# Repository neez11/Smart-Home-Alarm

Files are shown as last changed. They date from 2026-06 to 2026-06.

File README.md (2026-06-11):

# Smart Home Alarm

A local smart home alarm built with Raspberry Pi Zero WH, featuring PIR motion detection, LED and buzzer alarm feedback, Zigbee/MQTT door monitoring, camera support, a web dashboard and custom PCB design.

---

# Development
This project was developed as a group project in Electrical Engineering.

Contributors:
- [@neez11](https://github.com/neez11)
- [@abbefakih](https://github.com/abbefakih)
- [@MarcusAtaseven](https://github.com/MarcusAtaseven)
- [@Samy-Jomma](https://github.com/Samy-Jomma)

---

## Overview

This project is a smart home alarm prototype designed to run **locally without cloud services**.  
It combines embedded hardware, wireless communication, backend logic, a web-based dashboard, PCB design, and a 3D-printed enclosure into one complete system.

The system is built around a **Raspberry Pi Zero WH** and can:

- detect motion using a PIR sensor
- detect door/window events using a Zigbee sensor
- trigger local alarm feedback using LED and buzzer
- log events in the backend
- show live status in a web dashboard
- display a camera feed during alarm events
- run locally without relying on external cloud platforms

---

## Final Product

### Final assembled product
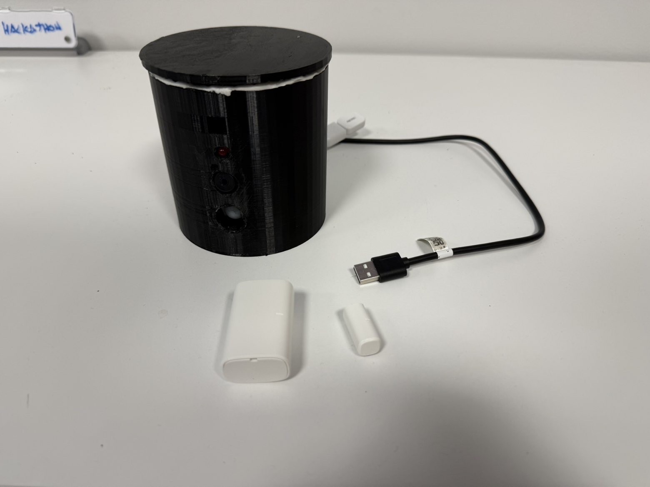
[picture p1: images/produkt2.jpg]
Final Product


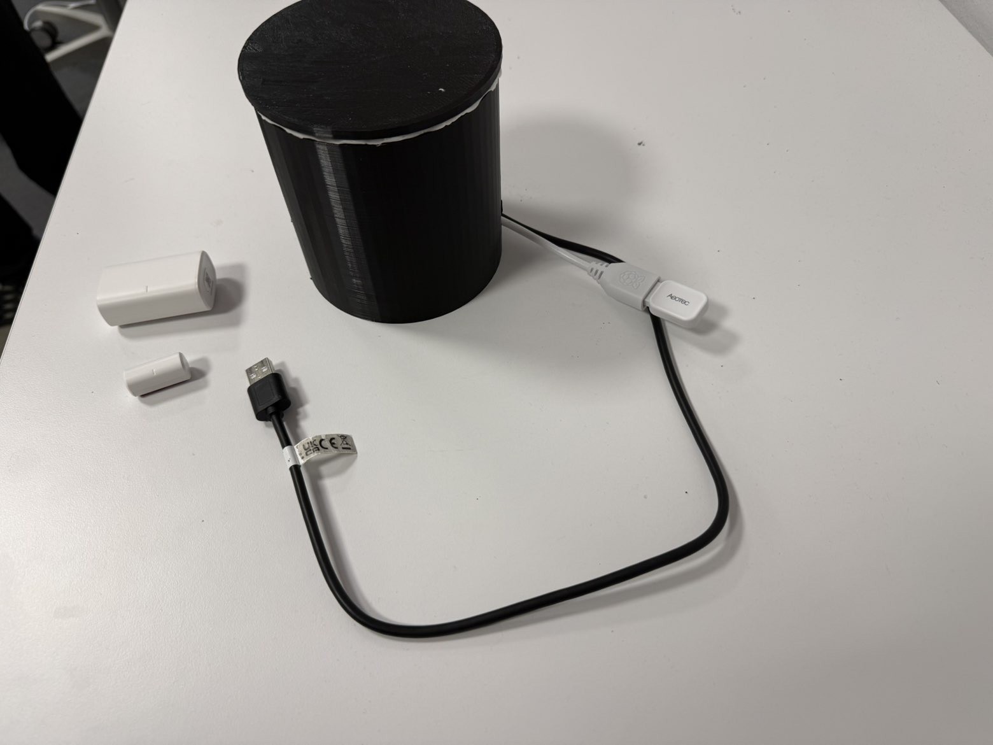
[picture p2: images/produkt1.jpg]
Final Product View


---

## Hardware Components

- Raspberry Pi Zero WH
- PIR sensor
- LED
- buzzer
- 220 Ω resistors
- SONOFF SNZB-04P Zigbee door/window sensor
- Zigbee USB adapter
- micro-USB OTG adapter
- Raspberry Pi camera module
- custom PCB
- 3D-printed enclosure

---

## System Architecture

The project is divided into the following parts:

### Local Hardware
- PIR sensor
- LED
- buzzer
- Raspberry Pi GPIO connections
- custom PCB

### Wireless Sensor Layer
- Zigbee door/window sensor
- Zigbee USB gateway
- Zigbee2MQTT
- MQTT messaging

### Software
- Python backend
- alarm logic
- event logging
- camera service
- REST API

### User Interface
- React/Vite frontend
- live system status
- event timeline
- control buttons
- camera view

### Deployment
- local hosting on Raspberry Pi
- Nginx as web server / reverse proxy

---

## Hardware Prototype

### Prototype wiring and components
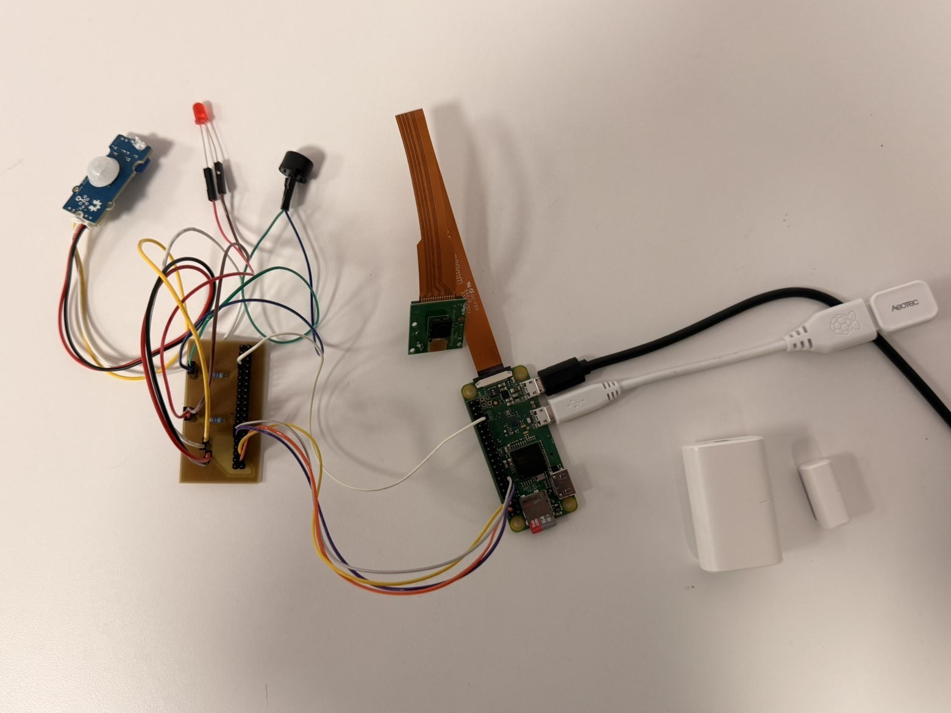
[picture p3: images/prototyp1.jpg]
Prototype


### Raspberry Pi GPIO reference
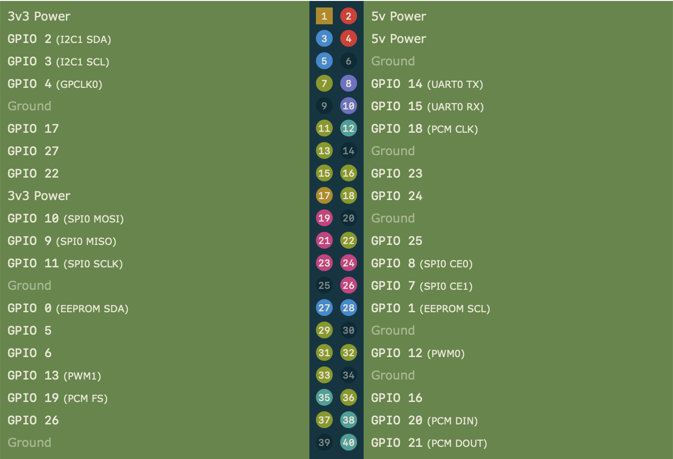
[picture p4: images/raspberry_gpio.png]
GPIO Pinout


---

## Schematic and PCB Design

The PCB was designed in **KiCad** based on the local hardware part of the system.

### KiCad schematic
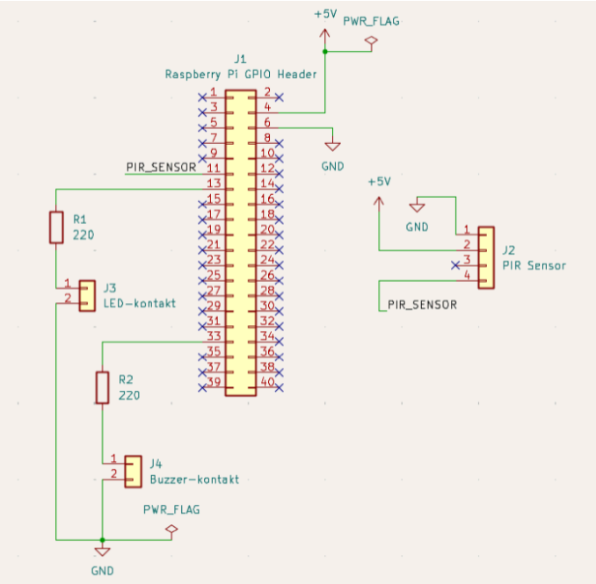
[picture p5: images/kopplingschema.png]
Schematic


### PCB layout
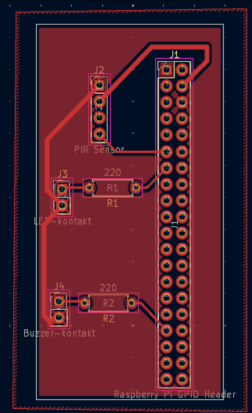
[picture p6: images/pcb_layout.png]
PCB Layout


### Manufactured PCB
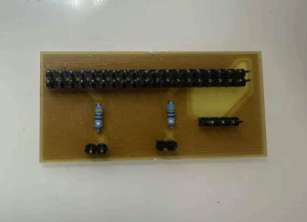
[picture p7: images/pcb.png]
PCB


The PCB includes the local electronics for:

- Raspberry Pi header
- PIR sensor connection
- LED connection
- buzzer connection
- resistors

The camera and Zigbee door sensor are handled separately and are not mounted directly on the PCB.

---

## 3D Enclosure Design

A custom enclosure was designed to make the prototype more compact and easier to demonstrate.

### Enclosure lid CAD
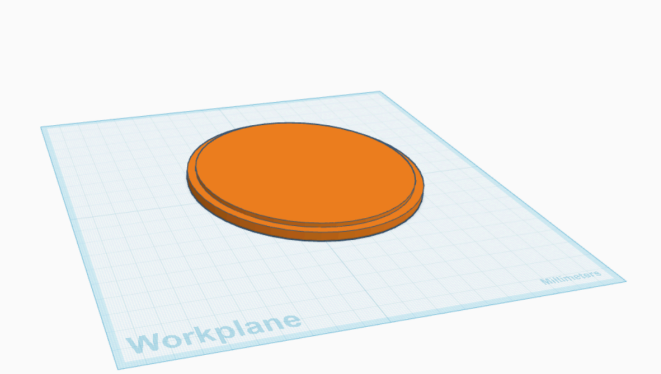
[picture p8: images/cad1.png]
CAD Lid


### Main enclosure CAD
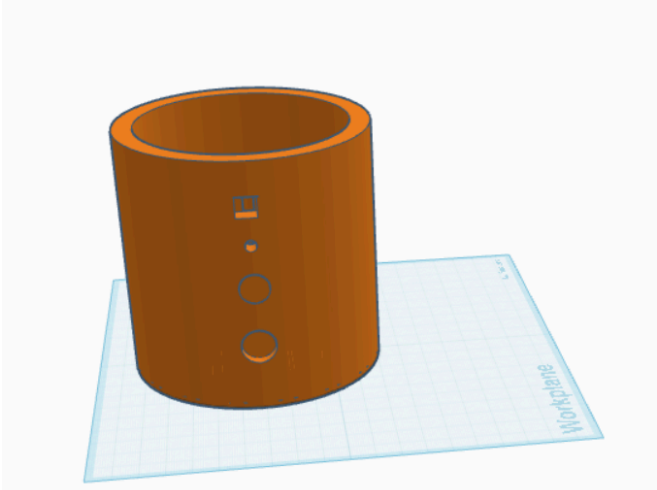
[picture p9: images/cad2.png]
CAD Enclosure


---

## How the System Works

1. The Raspberry Pi continuously monitors the PIR sensor and listens for door sensor events.
2. If motion is detected or the door opens while the system is armed:
   - the alarm state is triggered
   - LED and buzzer are activated
   - the event is logged
   - the web dashboard updates automatically
   - the camera can be used for visual verification
3. The user can monitor and control the system through the local web interface.

---

## Network Communication

The door/window sensor is not connected directly to the GPIO pins.  
Instead, it communicates wirelessly over **Zigbee**.

The communication flow is:

`Door Sensor -> Zigbee -> Zigbee USB Adapter -> Zigbee2MQTT -> MQTT -> Python Backend -> Frontend`

The PIR sensor, LED, and buzzer are connected locally to the Raspberry Pi.

---

## Web Dashboard

The web interface is used to monitor and control the system in real time.

It shows:

- alarm status
- motion status
- door status
- LED status
- buzzer status
- camera status
- event log
- control buttons for arm / disarm / reset / test

### Login page
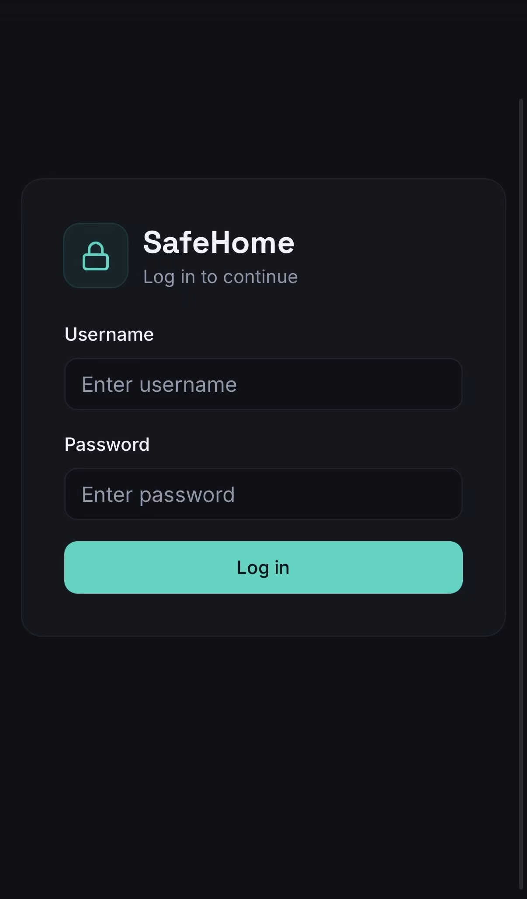
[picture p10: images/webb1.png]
Login Page


### Dashboard overview
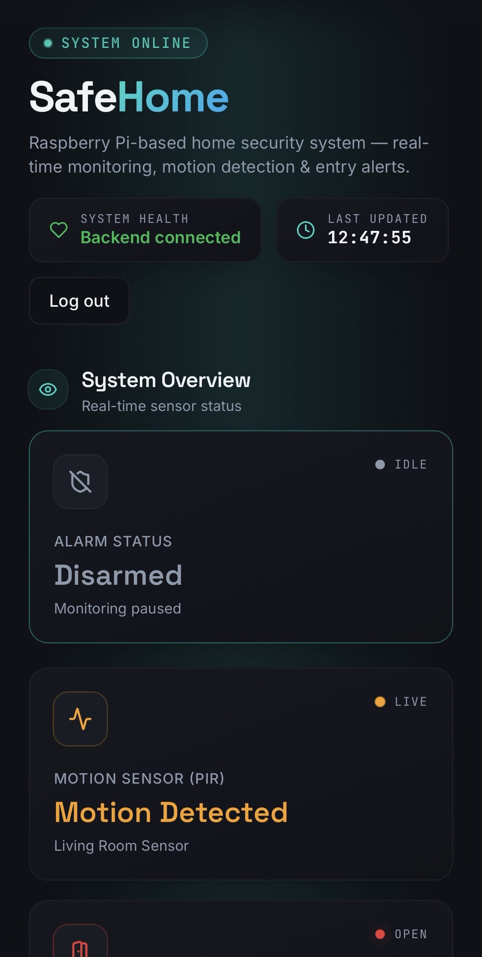
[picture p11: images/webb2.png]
Dashboard Overview


### Control panel and standby camera area
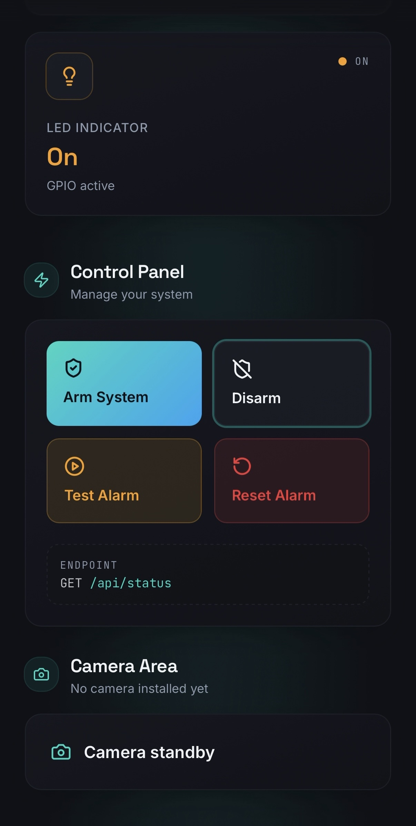
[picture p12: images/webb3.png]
Control Panel


### Alarm camera view
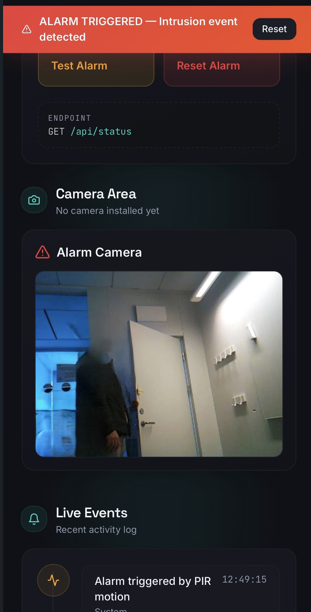
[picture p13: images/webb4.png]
Alarm Camera


### Live event log
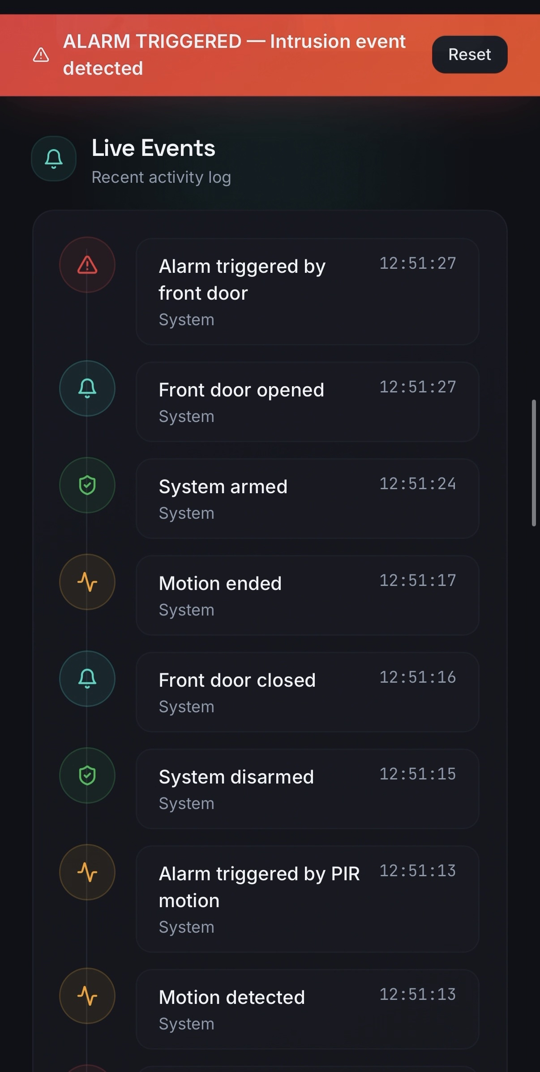
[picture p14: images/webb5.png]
Live Events


### Hardware status section
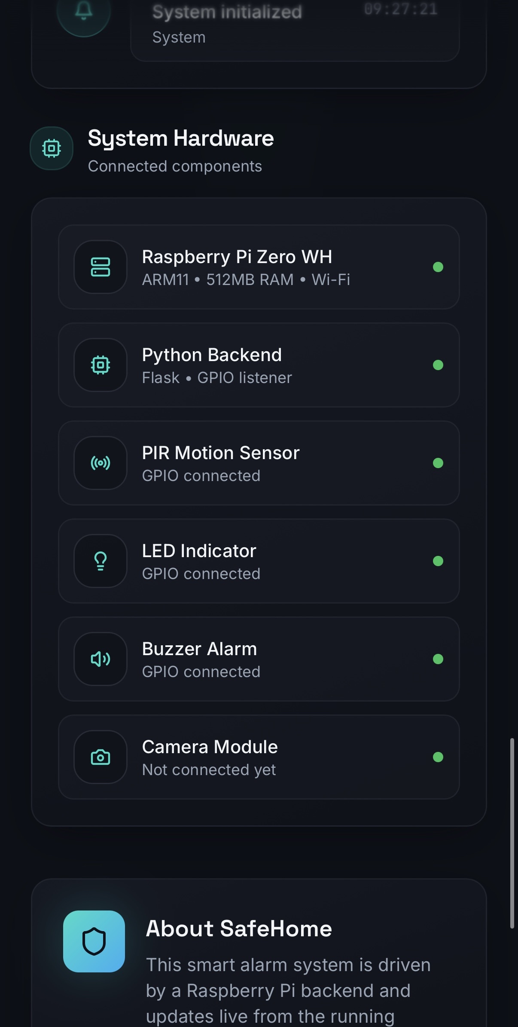
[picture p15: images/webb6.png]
Hardware Status


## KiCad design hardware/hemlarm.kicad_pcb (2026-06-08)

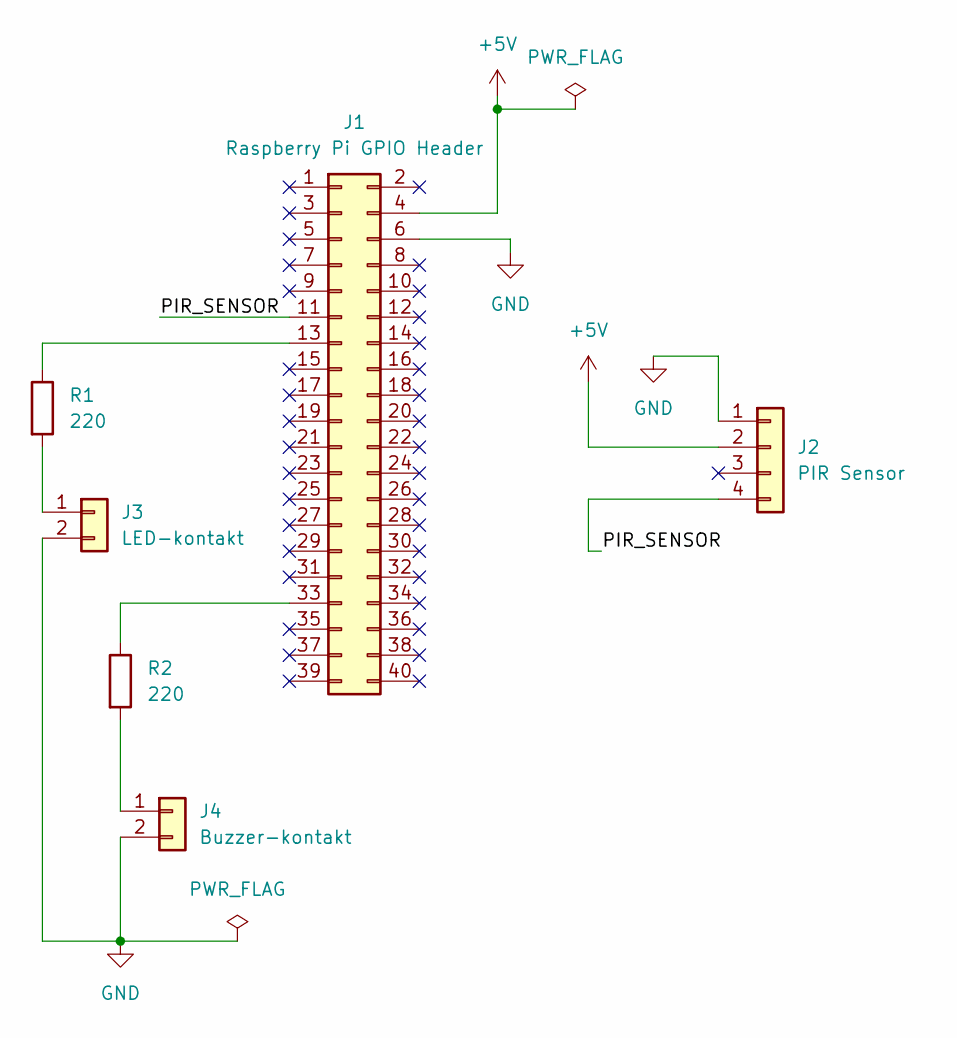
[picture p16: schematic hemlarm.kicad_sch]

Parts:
J1: Raspberry Pi GPIO Header; PinHeader_2x20_P2.54mm_Vertical
J2: PIR Sensor; PinHeader_1x04_P2.54mm_Vertical
J3: LED-kontakt; PinHeader_1x02_P2.54mm_Vertical
J4: Buzzer-kontakt; PinHeader_1x02_P2.54mm_Vertical
R1, R2: 220; R_Axial_DIN0207_L6.3mm_D2.5mm_P7.62mm_Horizontal

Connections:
+5V: J1.4, J2.2
/PIR_SENSOR: J1.11, J2.4
GND: J1.6, J2.1, J3.2, J4.2
unnamed: J1.13, R1.1
unnamed: J1.33, R2.1
unnamed: J3.1, R1.2
unnamed: J4.1, R2.2

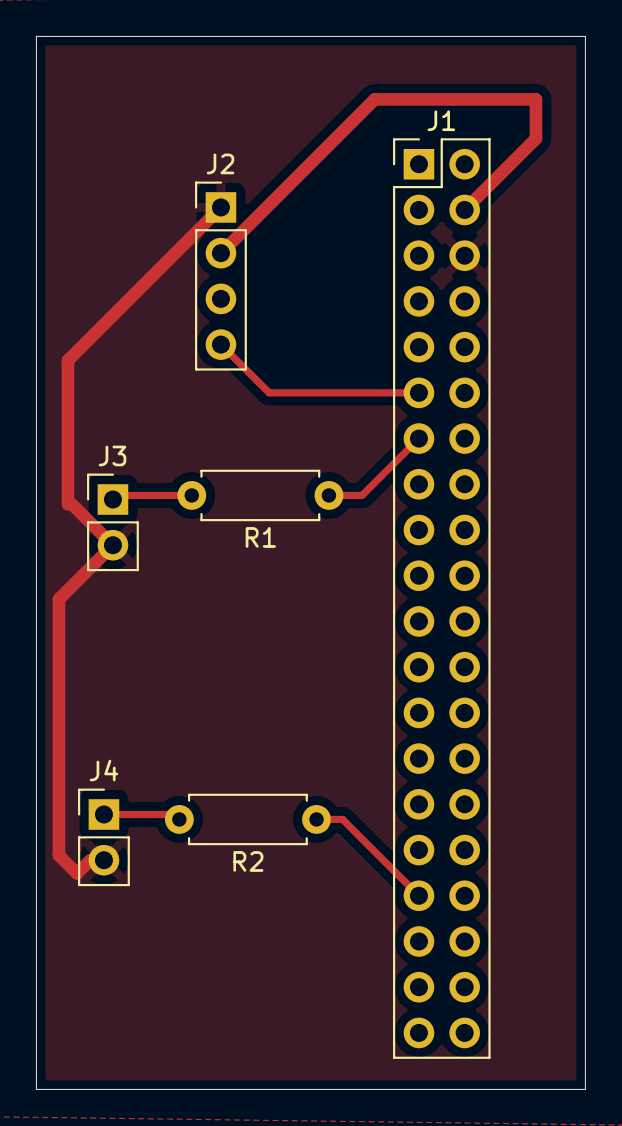
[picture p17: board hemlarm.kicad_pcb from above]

Board: 2 copper layers, 30.5 x 58.5 mm, 6 parts (0 on the bottom side), 7 nets.

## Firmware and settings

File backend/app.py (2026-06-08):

# app.py
from smart_alarm.buzzer import BuzzerService
from smart_alarm.zigbee_door_listener import ZigbeeDoorListener
from flask import Flask, jsonify, Response
from flask_cors import CORS

from config import (
    API_HOST,
    API_PORT,
    DEBUG,
    EVENT_LIMIT,
    GPIO_BUZZER,
    ENABLE_BUZZER,
    ZIGBEE_MQTT_ENABLED,
    ZIGBEE_MQTT_BROKER,
    ZIGBEE_MQTT_PORT,
    ZIGBEE_MQTT_TOPIC,
)
from smart_alarm.logger import setup_logger
from smart_alarm.system_state import SystemState
from smart_alarm.pir_sensor import PirAlarmController
from smart_alarm.camera_service import CameraService

logger = setup_logger()
state = SystemState(event_limit=EVENT_LIMIT)
buzzer = BuzzerService(pin=GPIO_BUZZER) if ENABLE_BUZZER else None
controller = PirAlarmController(state=state, logger=logger, buzzer=buzzer)
camera_service = CameraService(logger=logger, state=state)
door_listener = ZigbeeDoorListener(
    state=state,
    logger=logger,
    controller=controller,
    broker_host=ZIGBEE_MQTT_BROKER,
    broker_port=ZIGBEE_MQTT_PORT,
    topic=ZIGBEE_MQTT_TOPIC,
) if ZIGBEE_MQTT_ENABLED else None

app = Flask(__name__)
CORS(app)


@app.route("/api/test-buzzer", methods=["POST"])
def api_test_buzzer():
    if buzzer is not None:
        buzzer.alarm_pattern()

    return jsonify({
        "ok": True,
        "message": "Buzzer test completed"
    }), 200


@app.route("/api/arm", methods=["POST"])
def api_arm():
    controller.arm()

    if buzzer is not None:
        buzzer.beep()

    return jsonify({
        "ok": True,
        "message": "System armed",
        "status": state.get_status()
    }), 200


@app.route("/api/disarm", methods=["POST"])
def api_disarm():
    controller.disarm()

    if buzzer is not None:
        buzzer.beep()

    return jsonify({
        "ok": True,
        "message": "System disarmed",
        "status": state.get_status()
    }), 200


@app.route("/api/health", methods=["GET"])
def api_health():
    return jsonify({
        "ok": True,
        "service": "smart-hemlarm-backend"
    }), 200


@app.route("/api/status", methods=["GET"])
def api_status():
    return jsonify(state.get_status()), 200


@app.route("/api/events", methods=["GET"])
def api_events():
    return jsonify({
        "events": state.get_events()
    }), 200


@app.route("/api/reset", methods=["POST"])
def api_reset():
    controller.reset_alarm()

    return jsonify({
        "ok": True,
        "message": "Alarm reset",
        "status": state.get_status()
    }), 200


@app.route("/api/test", methods=["POST"])
def api_test():
    controller.test_outputs(duration=1.0)

    return jsonify({
        "ok": True,
        "message": "Output test completed",
        "status": state.get_status()
    }), 200


@app.route("/api/camera-stream")
def camera_stream():
    from time import sleep

    def generate():
        while True:
            status = state.get_status()

            if not status.get("alarm_triggered", False):
                break

            frame = camera_service.get_latest_image_bytes()
            if frame is None:
                sleep(0.2)
                continue

            yield (
                b"--frame\r\n"
                b"Content-Type: image/jpeg\r\n\r\n" + frame + b"\r\n"
            )

            sleep(0.2)

    response = Response(
        generate(),
        mimetype="multipart/x-mixed-replace; boundary=frame"
    )
    response.headers["Cache-Control"] = "no-store, no-cache, must-revalidate, max-age=0"
    response.headers["Pragma"] = "no-cache"
    response.headers["Expires"] = "0"
    return response

def main():
    logger.info("Starting backend on %s:%s", API_HOST, API_PORT)
    state.add_event("Backend starting")

    controller.start()

    if door_listener is not None:
        door_listener.start()

    if buzzer is not None:
        buzzer.beep()

    try:
        app.run(host=API_HOST, port=API_PORT, debug=DEBUG, threaded=True, use_reloader=False)
    finally:
        if door_listener is not None:
            door_listener.stop()

        controller.stop()
        logger.info("Backend stopped")



if __name__ == "__main__":
    main()

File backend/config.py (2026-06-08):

# config.py

# GPIO-konfiguration för NUVARANDE inkoppling
# Ni sa sist att PIR sitter på GPIO 17 och LED på GPIO 27.
GPIO_PIR = 17
GPIO_LED = 27
GPIO_BUZZER = 13
GPIO_DOOR = 18

API_HOST = "0.0.0.0"
API_PORT = 5000
DEBUG = False

POLL_INTERVAL = 0.5
EVENT_LIMIT = 40

ENABLE_BUZZER = True
ENABLE_DOOR_SENSOR = False
DOOR_ACTIVE_IS_OPEN = True

ENABLE_CAMERA = True
CAMERA_WIDTH = 640
CAMERA_HEIGHT = 480
CAMERA_JPEG_QUALITY = 70
CAMERA_FPS = 5
CAMERA_STARTUP_DELAY = 1.0
CAMERA_IMAGE_PATH = "/tmp/smart_hemlarm_camera.jpg"
ZIGBEE_MQTT_ENABLED = True
ZIGBEE_MQTT_BROKER = "127.0.0.1"
ZIGBEE_MQTT_PORT = 1883
ZIGBEE_MQTT_TOPIC = "zigbee2mqtt/front_door"

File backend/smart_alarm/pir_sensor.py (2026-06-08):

# smart_alarm/pir_sensor.py

import time
import threading
from gpiozero import MotionSensor, LED
from smart_alarm.buzzer import BuzzerService

from config import (
    GPIO_PIR,
    GPIO_LED,
    GPIO_BUZZER,
    POLL_INTERVAL,
    ENABLE_BUZZER,
)
from smart_alarm.system_state import SystemState


class PirAlarmController:
    def __init__(self, state: SystemState, logger, buzzer: BuzzerService | None = None):
        self.state = state
        self.logger = logger

        self.running = False
        self.thread = None

        self.pir = MotionSensor(GPIO_PIR)
        self.led = LED(GPIO_LED)

        self.buzzer = buzzer if ENABLE_BUZZER else None

        self._last_motion_state = False

        self.led.off()
        self.state.set_led_on(False)

        if self.buzzer is not None:
            self.buzzer.off()
        self.state.set_buzzer_on(False)

    def start(self) -> None:
        if self.running:
            return

        self.running = True
        self.thread = threading.Thread(target=self._loop, daemon=True)
        self.thread.start()
        self.logger.info("PirAlarmController started")
        self.state.add_event("PIR controller started")

    def stop(self) -> None:
        self.running = False

        if self.thread is not None:
            self.thread.join(timeout=2)

        self._safe_outputs_off()
        self.logger.info("PirAlarmController stopped")
        self.state.add_event("PIR controller stopped")

    def arm(self) -> None:
        self.state.set_armed(True)
        self.state.set_motion_detected(False)
        self.state.set_alarm_triggered(False)
        self._safe_outputs_off()
        self.logger.info("System armed")
        self.state.add_event("System armed")

    def disarm(self) -> None:
        self.state.set_armed(False)
        self.state.set_motion_detected(False)
        self.state.set_alarm_triggered(False)
        self._safe_outputs_off()
        self.logger.info("System disarmed")
        self.state.add_event("System disarmed")

    def reset_alarm(self) -> None:
        self.state.set_motion_detected(False)
        self.state.set_alarm_triggered(False)
        self._safe_outputs_off()
        self.logger.info("Alarm reset")
        self.state.add_event("Alarm reset")

    def test_outputs(self, duration: float = 1.0) -> None:
        self.logger.info("Testing outputs")
        self.state.add_event("Output test started")

        self.led.on()
        self.state.set_led_on(True)

        if self.buzzer is not None:
            self.buzzer.on()
            self.state.set_buzzer_on(True)

        time.sleep(duration)

        self._safe_outputs_off()
        self.state.add_event("Output test finished")

    def _safe_outputs_off(self) -> None:
        self.led.off()
        self.state.set_led_on(False)

        if self.buzzer is not None:
            self.buzzer.off()
        self.state.set_buzzer_on(False)

    def _trigger_alarm(self, source: str = "PIR motion") -> None:
        self.state.set_motion_detected(True)
        self.state.set_alarm_triggered(True)

        self.led.on()
        self.state.set_led_on(True)

        if self.buzzer is not None:
            self.buzzer.on()
            self.state.set_buzzer_on(True)

        self.logger.warning("Alarm triggered by %s", source)
        self.state.add_event(f"Alarm triggered by {source}")

    def trigger_external_alarm(self, source: str) -> None:
        if not self.state.armed:
            return

        if self.state.alarm_triggered:
            return

        self._trigger_alarm(source)


    def _clear_motion_idle(self) -> None:
        self.state.set_motion_detected(False)

        if not self.state.alarm_triggered:
            self.led.off()
            self.state.set_led_on(False)

            if self.buzzer is not None:
                self.buzzer.off()
            self.state.set_buzzer_on(False)

    def _read_motion_safe(self):
        try:
            return self.pir.motion_detected
        except RuntimeError as exc:
            if "deque mutated during iteration" in str(exc):
                self.logger.warning("PIR read skipped due to gpiozero deque race")
                time.sleep(0.05)
                return None
            raise

    def _loop(self) -> None:
        while self.running:
            try:
                motion_now = self._read_motion_safe()

                if motion_now is None:
                    time.sleep(POLL_INTERVAL)
                    continue

                if motion_now != self._last_motion_state:
                    self._last_motion_state = motion_now

                    if motion_now:
                        self.logger.info("Motion detected")
                        self.state.add_event("Motion detected")

                        if self.state.armed:
                            self._trigger_alarm()
                        else:
                            self.state.set_motion_detected(True)
                            self.led.on()
                            self.state.set_led_on(True)
                    else:
                        self.logger.info("Motion ended")
                        self.state.add_event("Motion ended")
                        self._clear_motion_idle()

                time.sleep(POLL_INTERVAL)

            except Exception as exc:
                self.logger.exception("Error in PIR loop: %s", exc)
                self.state.add_event(f"PIR loop error: {exc}")
                time.sleep(1)

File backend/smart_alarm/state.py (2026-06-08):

import loggindg


def setup_logger(name="smart_alarm"):
    logger = logging.getLogger(name)
    logger.setLevel(logging.INFO)

    if logger.handlers:
        return logger

    formatter = logging.Formatter(
        "%(asctime)s | %(levelname)s | %(name)s | %(message)s"
    )

    stream_handler = logging.StreamHandler()
    stream_handler.setFormatter(formatter)

    logger.addHandler(stream_handler)
    logger.propagate = False

    return logger
find ~/project1 -name "*.py" | xargs grep -n "class SystemState"
nano ~/project1/smart_alarm/state.py
from collections import deque
from threading import Lock
from datetime import datetime


class SystemState:
    def init(self):
        self.lock = Lock()

        self.armed = False
        self.motion_detected = False
        self.alarm_triggered = False
        self.buzzer_active = False
        self.led_on = False
        self.camera_online = False
        self.last_updated = datetime.now().strftime("%H:%M:%S")

        self.events = deque(maxlen=50)

    def add_event(self, message, room="System", event_type="info", icon="shield"):
        with self.lock:
            self.events.appendleft({
                "id": str(datetime.now().timestamp()),
                "time": datetime.now().strftime("%H:%M:%S"),
                "message": message,
                "room": room,
                "type": event_type,
                "icon": icon,
            })
            self.last_updated = datetime.now().strftime("%H:%M:%S")

    def get_events(self):
        with self.lock:
            return list(self.events)

    def get_status(self):
        with self.lock:
            return {
                "armed": self.armed,
                "motion_detected": self.motion_detected,
                "alarm_triggered": self.alarm_triggered,
                "buzzer_active": self.buzzer_active,
                "led_on": self.led_on,
                "camera_online": self.camera_online,
                "last_updated": self.last_updated,
            }
